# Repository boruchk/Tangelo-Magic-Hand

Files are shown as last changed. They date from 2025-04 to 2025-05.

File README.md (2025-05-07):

# Tangelo-Magic-Hand

The Tangelo Magic Hand is a bluetooth device designed to act as a mouse, as well as being able to activate macros on computer systems, “smart” devices, and other similar HID-compatible devices.

We aim to achieve
- An alternative to keyboard/mouse, free your hands and still have intuitive control
- Accessible to people with disabilities and those with limited mobility
- Help ease musculoskeletal disorders, overcome dexterity hurdles 
- Carpal tunnel, Cubital tunnel, etc., assist Parkinson’s, etc.
- Lower cost, especially compared to other options on the market

Here is a [link](https://docs.google.com/presentation/d/1tcinS4h7PuItlyA79dWSSfzN5xG-6EcUMcvodp_LoMc/edit?usp=sharing) to the full breakdown of our project

## Hardware Set-Up

A [Fritzing](https://fritzing.org/) [project file](./docs/tangelo_prototype.fzz) is provided to demonstrate the hardware configuration for this device and allow for further extension.
Note this project file depends on Adafruit's [Fritzing Library](https://github.com/adafruit/Fritzing-Library).

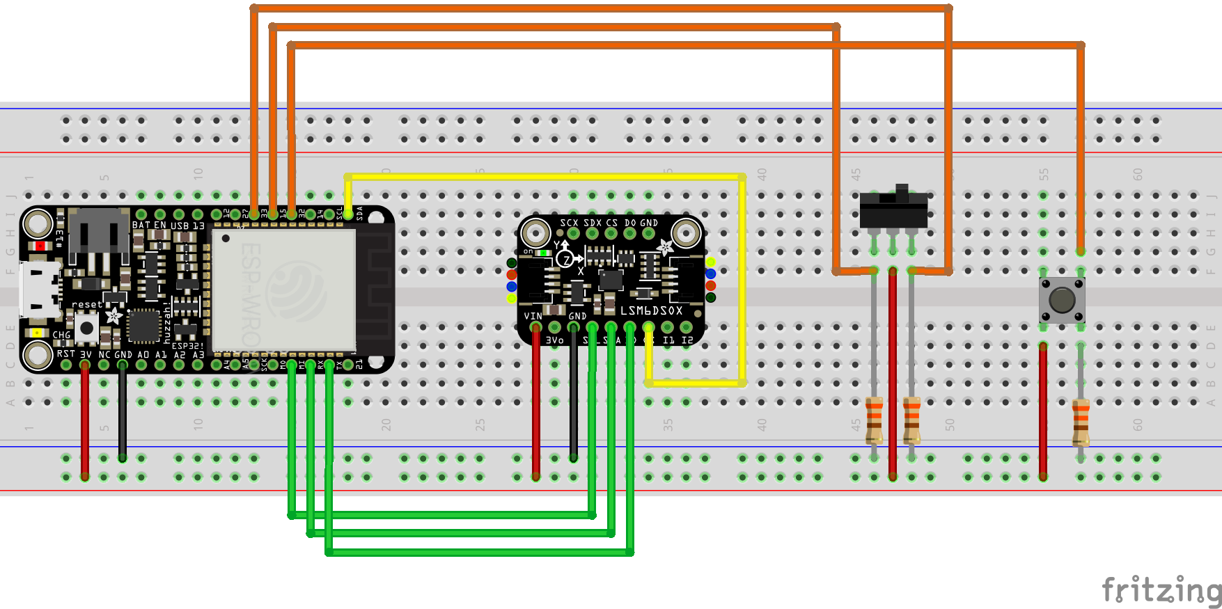
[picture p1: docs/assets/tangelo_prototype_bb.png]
breadboard


| esp32 pin | LSM6DSOX pin |
| ---| --- |
| 3v | VIN |
| GND | GND |
| MISO - clock | SCL |
| D16/RX - data out | SDA |
| D17/TX - data in  | DO |
| SDA - chip select | CS |

## Development Set-Up

- Download this repo to your local machine
- It is recommended to use Arduino for the ESP32 Feather Based on recommendations from [Adafruit website](https://learn.adafruit.com/adafruit-huzzah32-esp32-feather/using-with-arduino-ide)
- You can use the instructions from the [Espressif website](https://docs.espressif.com/projects/arduino-esp32/en/latest/installing.html)

## Compilation

- Partition Scheme
  - It's recommended to use one of the `No OTA` options (under `Tools`) to avoid having libraries bottlenecked by programmable storage space; statistics are provided below.
    - Using `No OTA (2MB APP/2MB SPIFFS)`, 54% of programmable storage space.
    - Using `Default 4MB with spiffs (1.2MB APP/1.5 SPIFFS)`, 87% of programmable space.

## BLE Technical information (some adopted from [ESP BLE Guide](https://github.com/nkolban/esp32-snippets/blob/master/Documentation/BLE%20C%2B%2B%20Guide.pdf))

While our project implements the [arduino-esp32](https://github.com/espressif/arduino-esp32) library with high level code, it is based on the more low level [ESP-idf repo](https://github.com/espressif/esp-idf).

We optimized the BLE header files by cutting down on the features that are not used in our device including (...)

### Put optimized files in the corresponding folders in the "libraries" directory

We create the server, we create the service, create a haracteristic upon the service,\\
set a value for the characteristic and then ask the service to start responding to incoming requests.

When a BLE Server is running, what must happen next is that peer devices (clients) must be able to\\
locate it. This is made possible through the notion of advertising. The BLE Server can broadcast its\\
existence along with sufficient information to allow a client to know what services it can provide.

Once we have started the BLE Server, we can ask it for an object (BLEAdvertising) that owns the\\
advertisements that the server produces:

```c++
BLEAdvertising* pAdvertising = pServer->getAdverstising();
pAdvertising->start();
```

Once performed, the server can be dynamically found by the clients. Of course a server doesn't need to\\
advertise. If a client should otherwise be informed (or remember) the address of the BLE server, it can\\
request a connection at any time.

Notify is used to signal (or notify) to the client that the characteristic's value has changed.\\
The client will receive an indication event to let it know that the change has occurred.\\
(indicate() receives a confirmation while a notify() does not receive a confirmation.)

```c++
pCharacteristic->setValue("HighTemp");
pCharacteristic->notify();
```

Associated with the idea of indications/notifications, is the architected BLE Descriptor called "Client
Characteristic Configuration" which has UUID 0x2902. This contains (among other things) two distinct
bit fields that can be on or off. One bit field governs Notifications while the other governs Indications.
If the corresponding bit is on, then the server can/may send the corresponding push.

For example if the Notifications bit is on, then the server can/may send notifications. The primary purpose of the
descriptor is to allow a partner (a client) to request that the server actually send notifications or
indications.

## Communication Protocol

We chose to use the SPI protocol over I2C as it offers higher-speed speed and lower-latency communication, ideal for our application.

We optimized the SPI header files by cutting down on the features that are not used in our device including tempurature sensing and the pedometer.

## Technical Docs

[adafruit-huzzah32-esp32-feather](https://cdn-learn.adafruit.com/downloads/pdf/adafruit-huzzah32-esp32-feather.pdf)

[esp32_technical_reference_manual_en](https://www.espressif.com/sites/default/files/documentation/esp32_technical_reference_manual_en.pdf)

[lsm6dsox-and-ism330dhc-6-dof-imu](https://cdn-learn.adafruit.com/downloads/pdf/lsm6dsox-and-ism330dhc-6-dof-imu.pdf)

[lsm6dsox Datasheet](https://www.st.com/resource/en/datasheet/lsm6dsox.pdf)

[ESP BLE Guide](https://github.com/nkolban/esp32-snippets/blob/master/Documentation/BLE%20C%2B%2B%20Guide.pdf)

[GATT Security Server Walkthrough](https://github.com/espressif/esp-idf/blob/master/examples/bluetooth/bluedroid/ble/gatt_security_server/tutorial/Gatt_Security_Server_Example_Walkthrough.md)

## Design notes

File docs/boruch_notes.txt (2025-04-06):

https://embeddedcentric.com/lesson-2-ble-profiles-services-characteristics-device-roles-and-network-topology/
https://punchthrough.com/manage-ble-connection/

https://github.com/espressif/arduino-esp32/blob/master/libraries/BLE/src/BLEServer.h

  BLE sends data as messages called a charactaristic (BLECharacteristic)
  Each charactaristic optionally has a descriptor (BLE2902) with more info about the charactaristic
  
  Breakdown of BLE Hierarchy:
    Server = this device, which contains (allows for discovery) one or more services
    Service = Contains related characteristics.
      HID Service (0x1812)
    Characteristic = A data point which contains declaration and value attributes.
    Value = The actual data
    Declaration = Metadata about the actual data:
    - Characteristic value UUID, UUID = type of charactaristic could be either a standard Bluetooth-SIG defined UUID (16-bits) or a vendor specific UUID (128-bits)
    - Characteristic value handle = client needs this to grab the data (like a data address)
    - Characteristic properties = Lists the GATT operation(s) allowed on the characteristic value:
      ~ Broadcast
      ~ Read = client can read
      ~ Write with no responce = No acknowledgment is sent from the server (saves power but maybe not reliable)
      ~ Write = expects ack
      ~ Notify = server sends data (no ack)
      ~ Indicate = server sends data (yes ack)
      ~ Authenticated Signed Write = allows the server to verify the authenticity “signature” of the data and confirm its source (requires paring and bonding)
    Descriptor = Metadata that provides extra information about the characteristic.
      The second use for the descriptor, which is the most commonly used is to use it as a switch to turn ON/OFF indication and notification (server-initiated updates). This type of descriptors is known as Client Characteristic Configuration Descriptor(CCCD).

  Device sends advertisements to PC that it's ready to connect to a client
  Device listens for PC Scan or Connection Request
  Device responds to a Scan Request with a Scan Response (another advert), and the client completes the connection (and pairing/bonding if the client has the capability)

  Advertisement:
  - advert interval: use a fast interval (under a few hundred milliseconds) for a short duration (e.g. 30 seconds) at Peripheral power-up, 
    upon disconnection, or upon a user event. After 30 or more seconds, reduce the advertising interval
  - peripheral latency: 
  - supervision timeout: 
  Most stacks use a default connection interval of under 100 milliseconds and a peripheral latency of 0
  Make long connection interval and low latency when connecting or sending lots of data, Reduce when in normal running mode

  Transmit power: Change advertising TX power and TX power while in a connection to increase battery life
    Enable the LE Power Control feature if available.

  If sleeping is not be viable, use longer advertising intervals and/or connection parameters

  Use LE Privacy in which the Peripheral’s advertisement address changes at a configurable interval

  Bonding or application-level authentication can prevent unauthenticated devices from exchanging data with your device

  Filter Accept List: The Peripheral adds the Central to its Filter Accept List after making a connection for the first time
    prevents unauthorized centrals to connect

See report structure documentation here:
This document describes the Human Interface Device (HID) class for use with Universal Serial Bus (USB)
https://usb.org/sites/default/files/hid1_11.pdf

This document defines constants that can be interpreted by an application to identify the purpose and meaning of a data field in a HID report.
https://usb.org/document-library/hid-usage-tables-16

usage = 32 bits
- ID = bits 0-15 of the 4-byte data portion
- page = bits 16-31 of the data portion

usage describes:
- controls = state of a device (on/off, enable/disable)
- collections = group related controls and data together
- data = remaining information that is passed between a device and the host

https://github.com/T-vK/ESP32-BLE-Mouse/tree/master
https://github.com/nkolban/esp32-snippets/issues/230#issuecomment-473135679

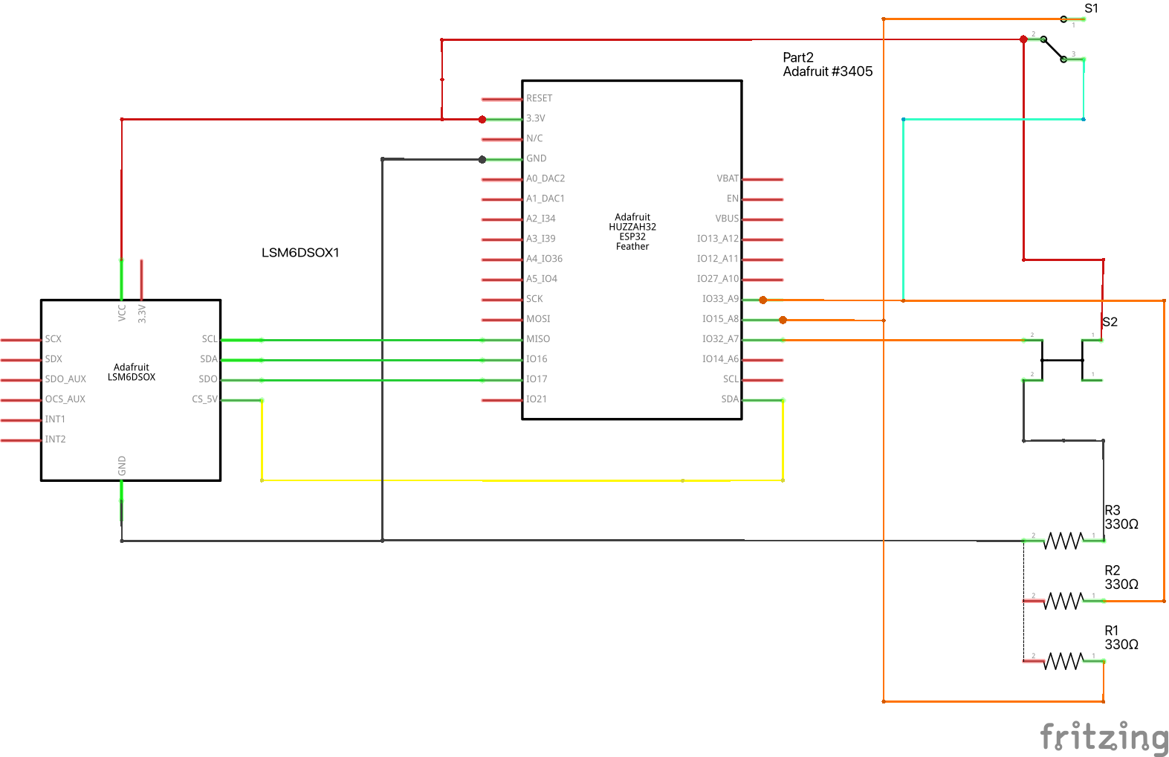
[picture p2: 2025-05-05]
docs/assets/tangelo_prototype_schem.png

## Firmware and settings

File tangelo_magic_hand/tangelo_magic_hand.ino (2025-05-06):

/* 
TODO:
- Figure out how to:
  - Make long connection interval and low latency when connecting or sending lots of data, Reduce when in normal running mode
  - Change advertising TX power and TX power while in a connection to increase battery life 
    Enable the LE Power Control feature if available
- Make a sleep function that for when device is inactive (if possible)
  - Make check in loop() that checks for 
- Set up ability to show battery percentage
*/

#include "bluetooth_setup.h"
#include "sensor_setup.h"

// Device pin constants 
#define ACCEL_MOUSE 33
#define GYRO_MOUSE 15
#define BUTTON_PIN 32

// Mouse button constants
#define MOUSE_LEFT 1
#define MOUSE_RIGHT 2
#define MOUSE_MIDDLE 4
#define MOUSE_BACK 8
#define MOUSE_FORWARD 16

// Gyroscope-related constants
#define ROT_X_BOUND PI / 5
#define ROT_Y_BOUND PI / 5
#define ROT_X_CORRECT 0.035f
#define ROT_Y_CORRECT 0.02f

// LSM6DSOX chip number 1
// Rename to "mouse", "Button", etc when finishing
AS_LSM6DSOX sox1;
AS_LSM6DSOX sox2;

float previous_time = 0.f;

signed char mouse_move_x = 0,
            mouse_move_y = 0,
            mouse_v_wheel = 0,
            mouse_h_wheel = 0;
uint8_t     mouse_button_press = 0;

float x_radians = 0.0f;
float y_radians = 0.0f;

int dt = 10;  // polling frequency in ms 

static inline void flush()
{
    if (can_communicate()) 
    {
        uint8_t mouse[5];
        mouse[0] = mouse_button_press;  // Button
        mouse[1] = mouse_move_x;        // Move in X
        mouse[2] = mouse_move_y;        // Move in Y
        mouse[3] = mouse_v_wheel;       // Vertical scroll
        mouse[4] = mouse_h_wheel;       // Horizontal scroll

        inputMouse->setValue(mouse, sizeof(mouse));
        inputMouse->notify();

        if (mouse_move_x != 0 || mouse_move_y != 0)
        {
            Serial.println("Moving mouse cursor:"); 
            Serial.println("X:"); 
            Serial.println(mouse_move_x);
            Serial.println("Y:"); 
            Serial.println(mouse_move_y);
        }
        if (mouse_button_press)
        {
            Serial.println("Performing mouse button press:");
            if (mouse_button_press == MOUSE_LEFT) Serial.println("Left click");
        }

        mouse_move_x = 0;
        mouse_move_y = 0;
        mouse_v_wheel = 0;
        mouse_h_wheel = 0;
        mouse_button_press = 0;
    }
}

static inline void use_button(uint8_t button) {
    mouse_button_press = button;
}

static inline void readGyro(AS_LSM6DSOX& sox, const int chipSelect) {
  if (can_communicate()) {
    // Select the chip
    digitalWrite(chipSelect, LOW);

    float time = (float) millis() / 1000;
    float delta_time = time - previous_time;
    previous_time = time;

    sensors_event_t accel;
    sensors_event_t gyro;

    sox.getEvent(&accel, &gyro);

    Serial.print("\t\tGyro: \n");
    Serial.println("X:");
    Serial.print(gyro.gyro.x);
    Serial.println(" rad/s ");

    float rot_x = gyro.gyro.x * delta_time;
    x_radians += rot_x;
    mouse_move_x = rot_x * 375;

    if (x_radians >= ROT_X_BOUND - ROT_X_CORRECT) {
        mouse_move_x = 15;
    }
    if (x_radians <= -ROT_X_BOUND + ROT_X_CORRECT) {
        mouse_move_x = -15;
    }

    Serial.println(x_radians);

    Serial.println("Y:");
    Serial.print(gyro.gyro.y);
    Serial.println(" rad/s ");

    float rot_y = gyro.gyro.y * delta_time;
    y_radians += rot_y;
    mouse_move_y = rot_y * 375;

    if (y_radians >= ROT_Y_BOUND - ROT_Y_CORRECT) {
        mouse_move_y = 15;
    }
    if (y_radians <= -ROT_Y_BOUND + ROT_Y_CORRECT) {
        mouse_move_y = -15;
    }

    Serial.println(y_radians);
    
    Serial.println("Z: ");
    Serial.print(gyro.gyro.z);
    Serial.println(" rad/s ");
    Serial.println();

    // Deselect the chip
    digitalWrite(chipSelect, HIGH);
  }
}


static inline void readAccel(AS_LSM6DSOX& sox, const int chipSelect) {
  Serial.println("Accelerometer not yet set up");
}


void setup() {
  Serial.begin(115200);

  pinMode(GYRO_MOUSE, INPUT);
  pinMode(ACCEL_MOUSE, INPUT);
  pinMode(BUTTON_PIN, INPUT);   

  bluetooth_setup();
  sensor_setup(sox1);
}
  

void loop() {
  advertize();

  // Use gyroscope to move the mouse
  if (digitalRead(GYRO_MOUSE) == HIGH) {
    // Zero the gyroscope reading
    if (digitalRead(BUTTON_PIN) == HIGH) {
        x_radians = 0.0f;
        y_radians = 0.0f;
    }

    digitalWrite(LSM_CS2, HIGH);
    readGyro(sox1, LSM_CS1);
  }
  // Use accelerometer to move the mouse
  else if (digitalRead(ACCEL_MOUSE) == HIGH) {
    digitalWrite(LSM_CS2, HIGH);
    readAccel(sox1, LSM_CS1);
  }

  if (checkForDoubleTap(sox1)) use_button(MOUSE_LEFT);
  
  flush();
  delay(dt);
}

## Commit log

2025-03-23 gitignore and arduino code (located in tangelo_magic_hand directory)
2025-04-06 added lots of documentation. improved connection reliability. made the device only send data when paired to the client. removed use of the heap.
2025-04-11 added support for SPI communication to the LSM6DSOX chip. added optimized sox chip header files in libraries directory. added some more documentation in the README
2025-04-11 removed example and i2c files from libraries directory
2025-04-12 integrated gyro with bluetooth mouse its working!!!!!!!!
2025-05-04 Refine gyroscope control and add calibration button
2025-05-05 separate bluetooth and sensor functions out of the main file. Combine Amani's and Ren's code
2025-05-05 Create `docs` folder, add Fritzing files and move notes
    [tangelo_prototype.fzz]
2025-05-05 Clean up code, adjust gyroscope control
2025-05-06 Adjust gyro mouse control
